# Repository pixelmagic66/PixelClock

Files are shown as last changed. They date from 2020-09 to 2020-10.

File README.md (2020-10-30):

# Pixelclock Dutch 11x9 1/4 

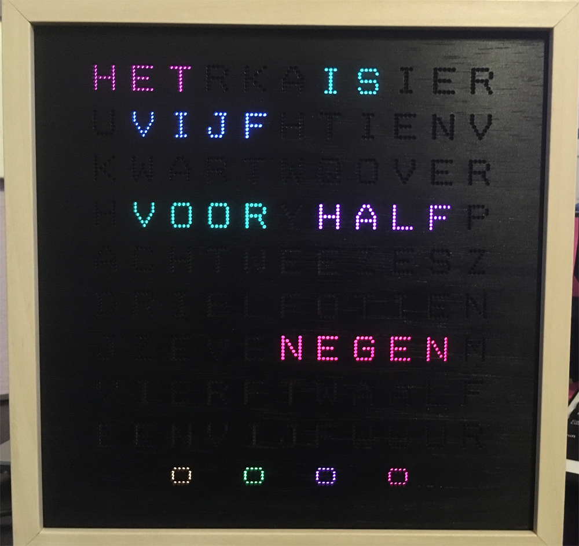
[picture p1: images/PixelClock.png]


Original software from https://github.com/bitlair/wordclock, all credits for the software and design go toward them.

Uses the now (2020) available Hovstra frame from Ikea https://www.ikea.com/nl/nl/p/hovsta-fotolijst-berkenpatroon-berken-80365755/

Adapted the internal frame structure and other font for the front of the clock.

I was a little bit puzzled by the uploading of the /data directory, this is what I did

- Follow the instructions from here: http://arduino.esp8266.com/Arduino/versions/2.0.0/doc/filesystem.html 
- I needed to set the adjust the flash size from 4mb to 3mb
- Upload the /data directory to SPIFFS (if I am correct), this takes some time

This is the other stuff you need te do:

- Upload the software from https://github.com/bitlair/wordclock or if you use my layout and connections use my code, using the Arduino IDE
- Connect your WS2812 led strip to the port specified in the code
- Configure the leds (if needed) in the leds tab of Arduino IDE
- Configure the words if you use other then I did (Dutch)
- Power up and via WiFi AP configure your WiFi network
- Enjoy the clock :)

The font I used is Dotrice found at https://www.1001fonts.com/dotrice-font.html if you need it for another language or layout, the svg file named Wordclock-face.svg

The first plan was to use spacers to add a white plexiglass layer to defuse the light. On the first test with this font and a piece of printer paper the defusion was good enough to not use the plexiglass. After that I redesigned the crossing layers to not use the spacers. 

So the order from back to front is:

- backplate with LED strips and wires on the back
- connecting brackets to isolate the LED's
- a piece of printer paper
- the frontplate, I spray painted it with black paint

Note on the svg files for the laser cutter, red lines ar cutting lines, blue lines are for etching (only used on the backside).

Materials I used:

- 103 pieces 60 led/meter WS2812 (AliExpress)
- Wemos type ESP8266
- 5 volt power brick
- 3mm bearch plywood (from the Gamma)
- Ikea Hovstra 23x23 photo frame
- black spraypaint (Ac-tion)

Tools used:

- Laser cutter (K40 type)
- K40 Whisperer
- Soldering iron
- Sanding paper
- Arduino IDE
- CorelDRAW! (for the front face)
- Inkscape (converting to usable date for K40 Whisperer)
- Fusion360 (the 3d design)

**

Uploading files to file system

ESP8266FS is a tool which integrates into the Arduino IDE. It adds a menu item to Tools menu for uploading the contents of sketch data directory into ESP8266 flash file system.

    Download the tool: https://github.com/esp8266/arduino-esp8266fs-plugin/releases/download/0.1.3/ESP8266FS-0.1.3.zip.
    In your Arduino sketchbook directory, create tools directory if it doesn't exist yet
    Unpack the tool into tools directory (the path will look like <home_dir>/Arduino/tools/ESP8266FS/tool/esp8266fs.jar)
    Restart Arduino IDE
    Open a sketch (or create a new one and save it)
    Go to sketch directory (choose Sketch > Show Sketch Folder)
    Create a directory named data and any files you want in the file system there
    Make sure you have selected a board, port, and closed Serial Monitor
    Select Tools > ESP8266 Sketch Data Upload. This should start uploading the files into ESP8266 flash file system. When done, IDE status bar will display SPIFFS Image Uploaded message.

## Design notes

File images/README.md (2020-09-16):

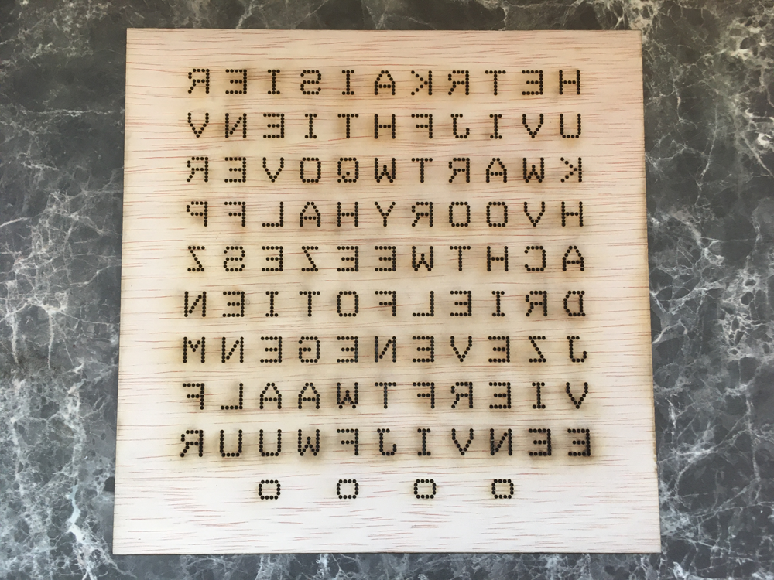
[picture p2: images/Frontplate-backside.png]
The backside of the front panel

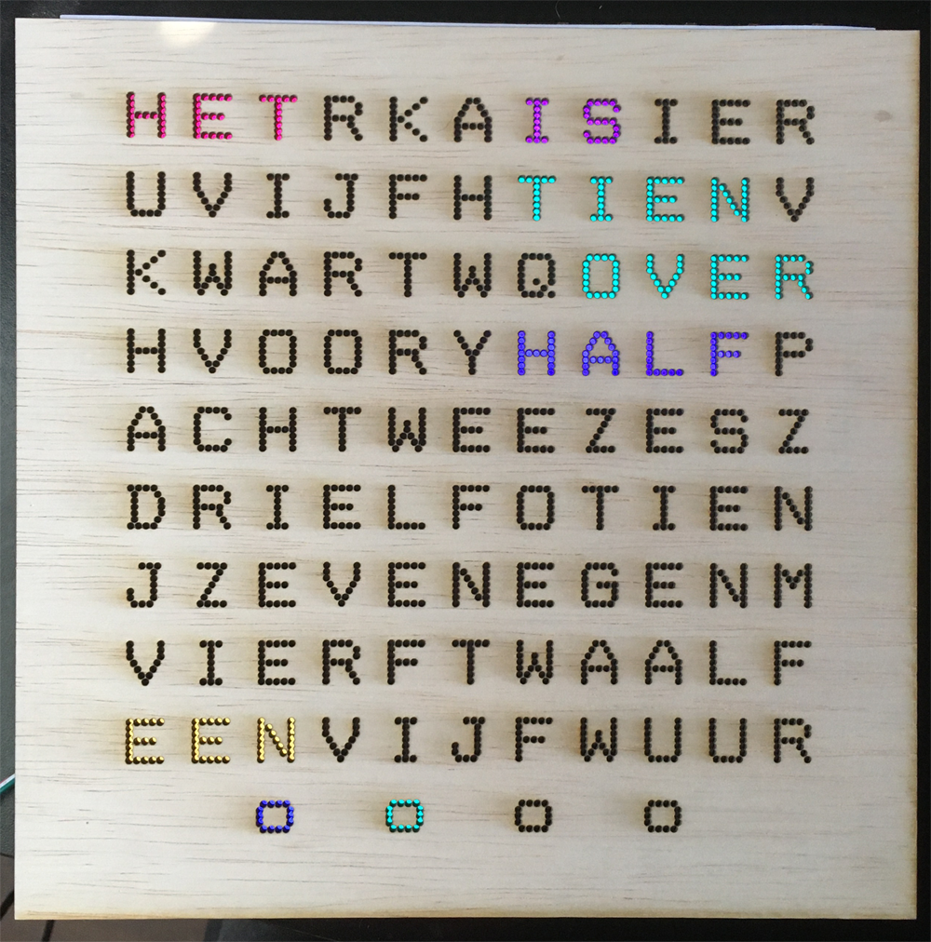
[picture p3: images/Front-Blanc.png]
The frontpanel without paint

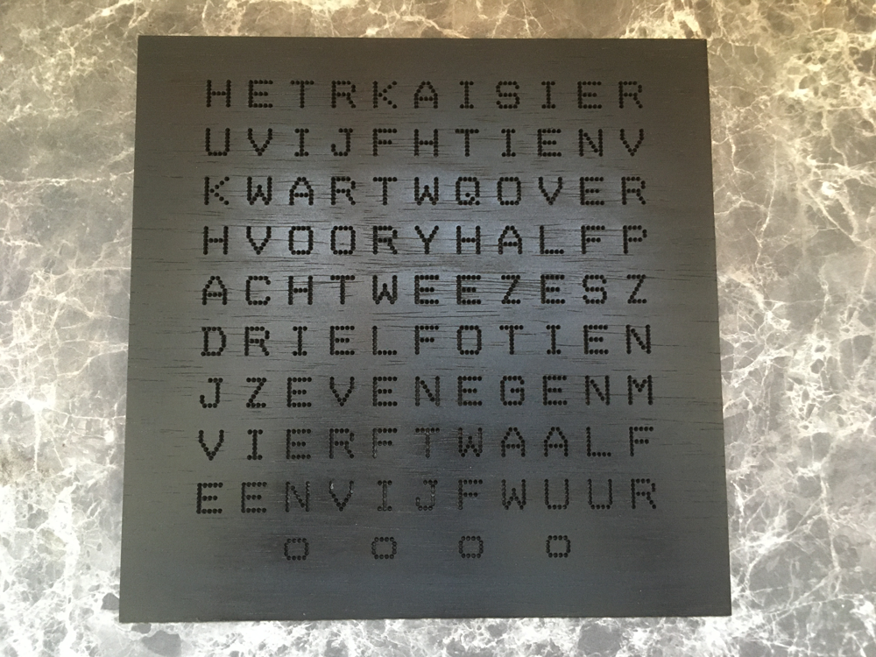
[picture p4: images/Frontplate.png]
The frontpanel with paint

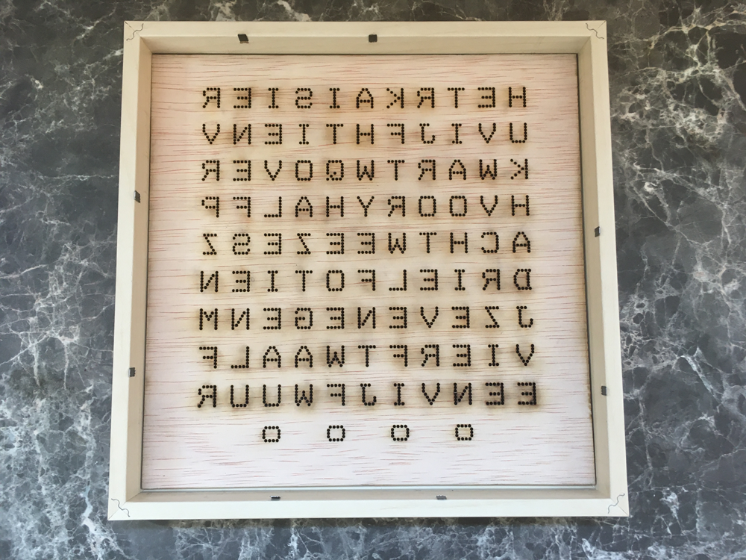
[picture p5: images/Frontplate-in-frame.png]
Frontpanel in the Ikea frame

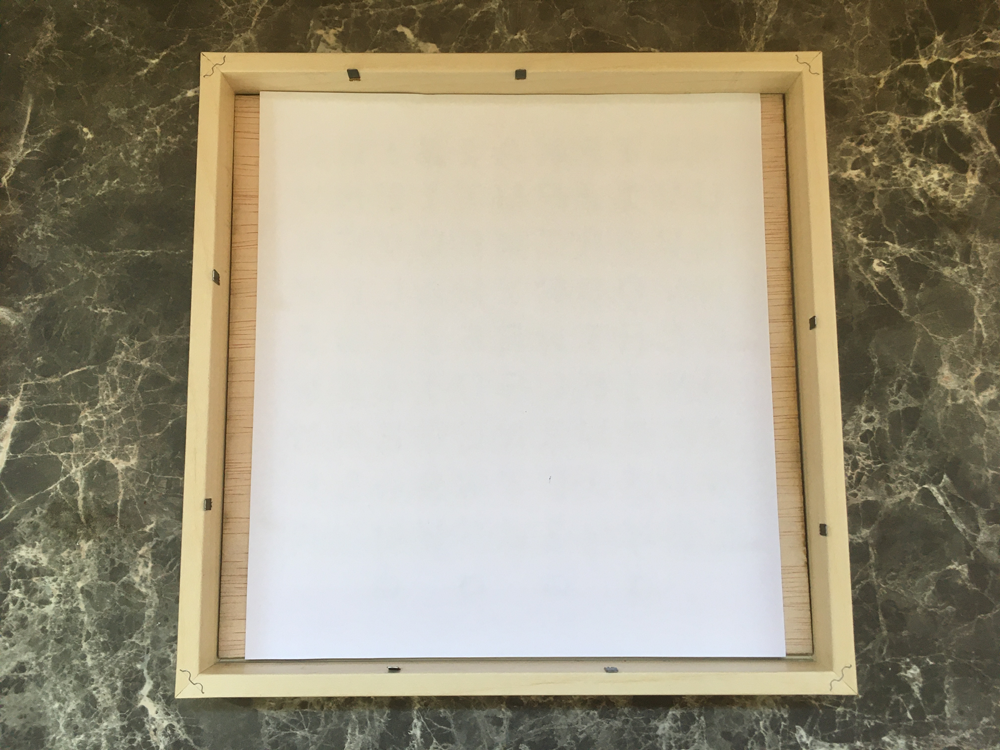
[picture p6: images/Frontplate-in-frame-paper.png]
A piece of printer paper to defuse the LEDs

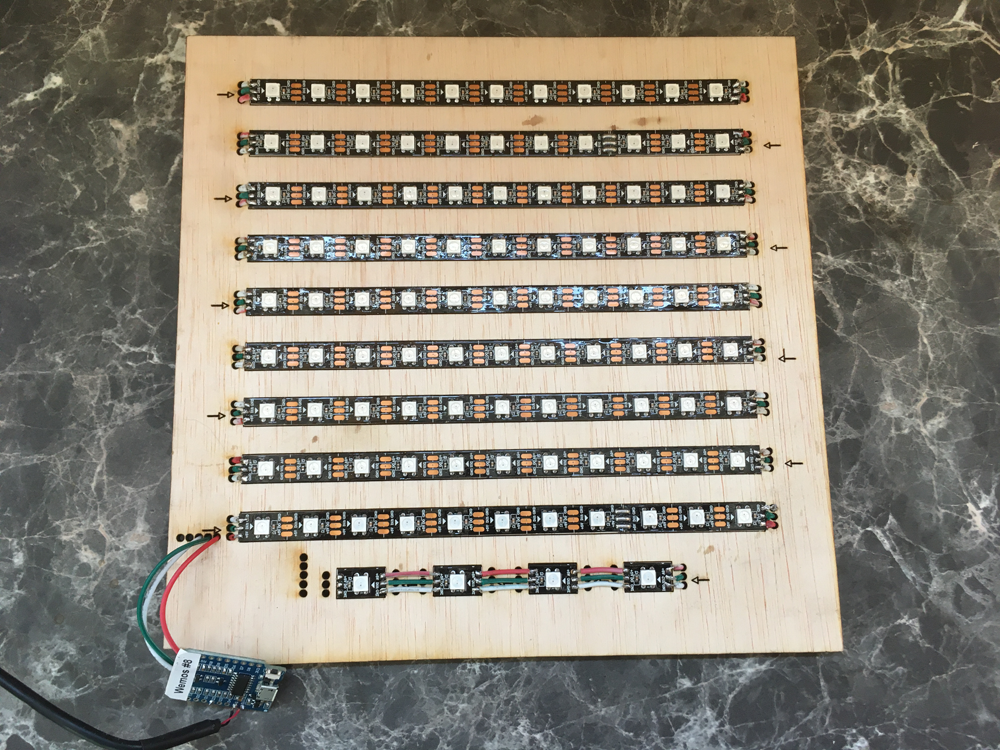
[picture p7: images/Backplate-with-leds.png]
The backplate with LED strips taped and soldered

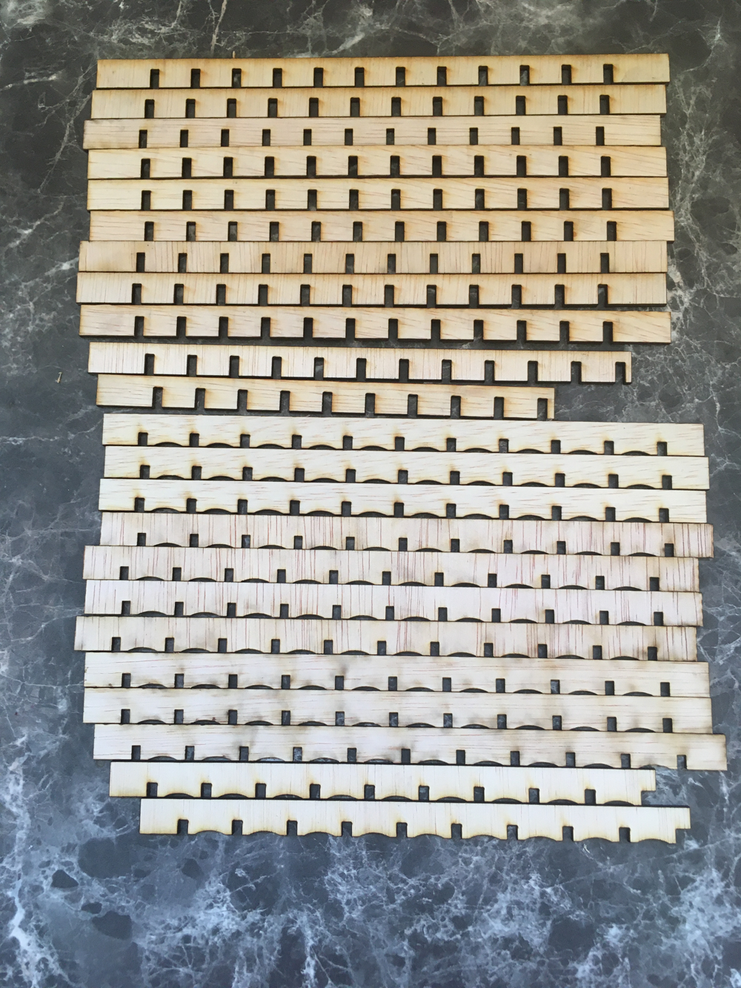
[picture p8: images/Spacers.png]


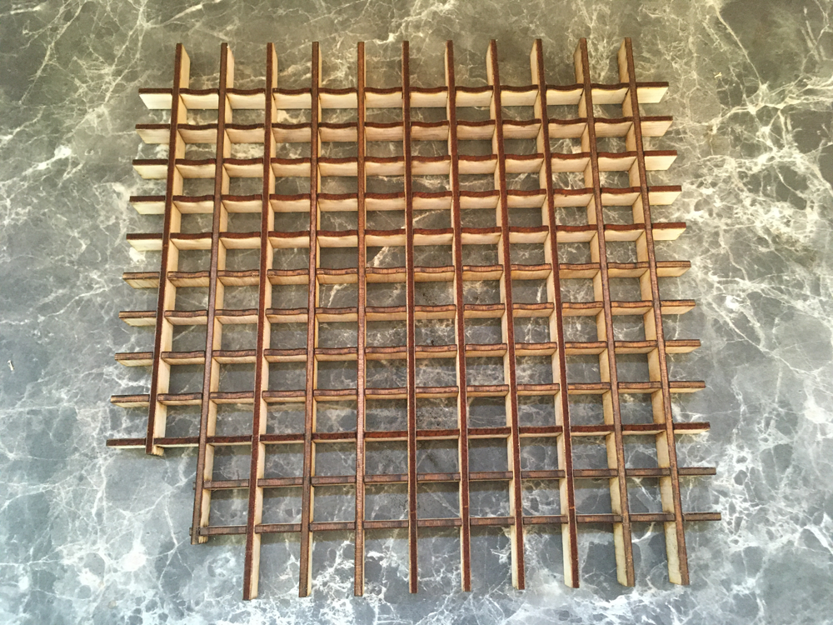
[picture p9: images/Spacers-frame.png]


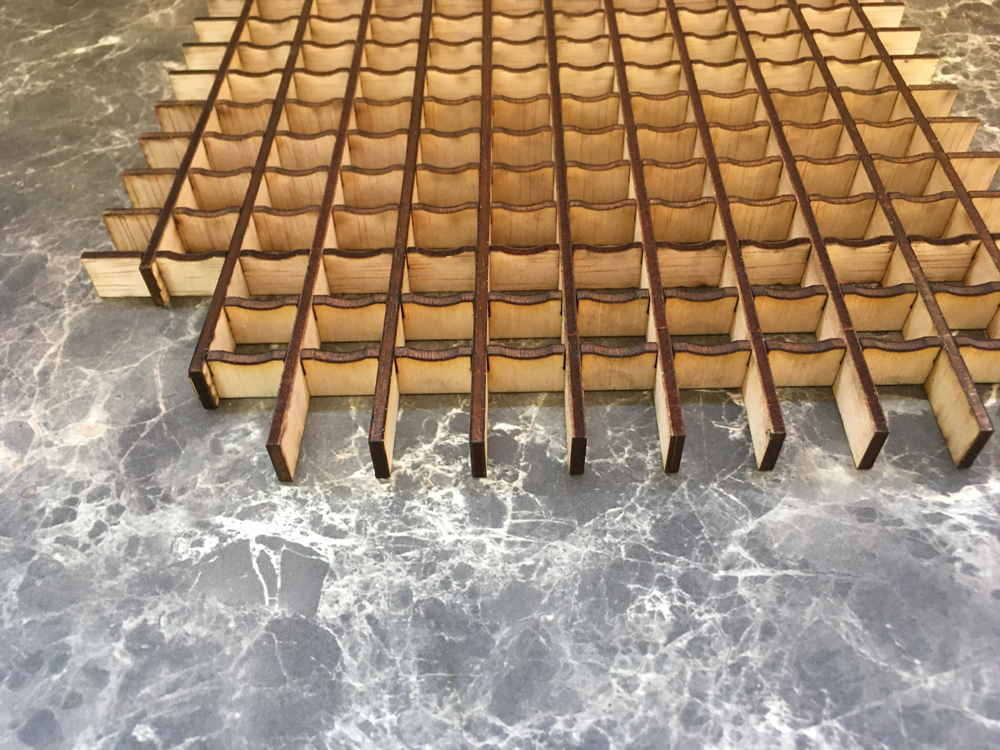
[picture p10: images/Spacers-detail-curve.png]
Beware of the curves for the LED strip, position in the correct way

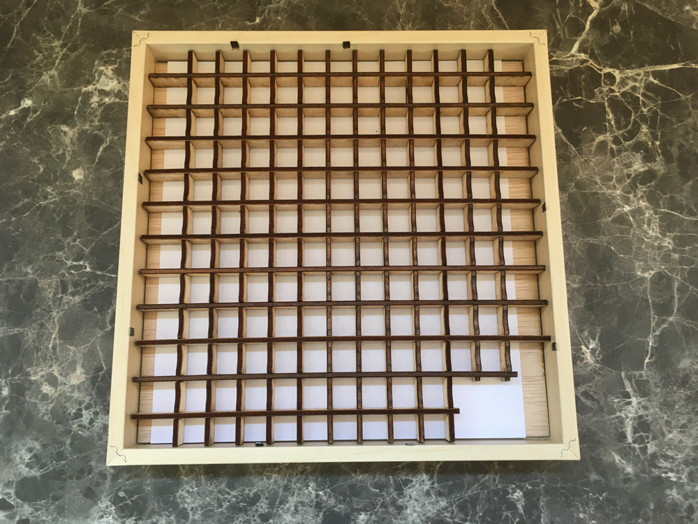
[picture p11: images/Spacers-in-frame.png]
The spacers in the frame, notice the space for the Wemos on the bottom right and the curvy spacing horizontal

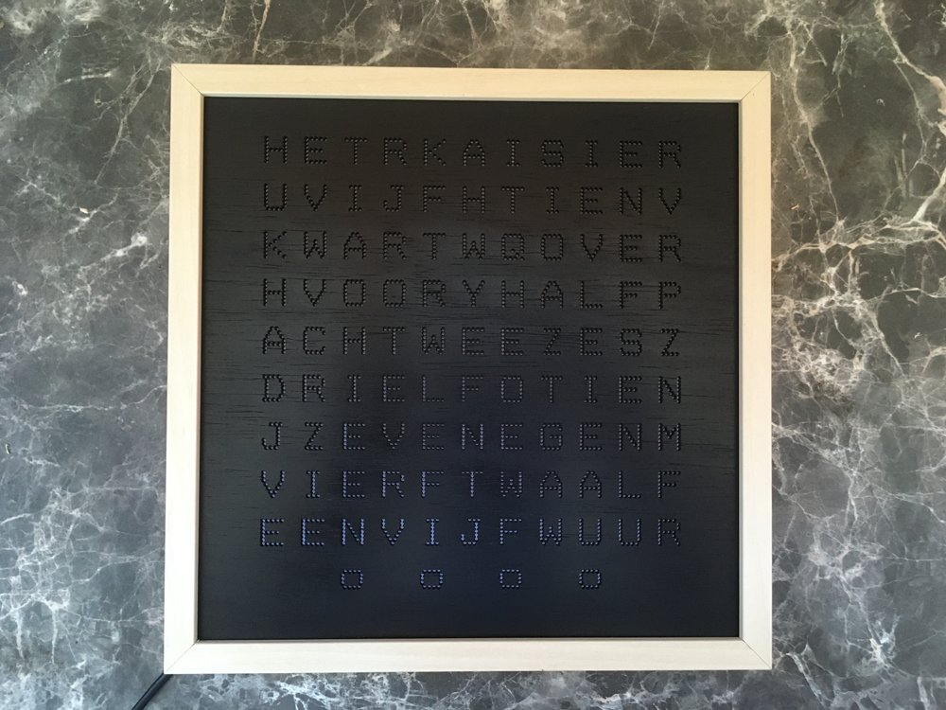
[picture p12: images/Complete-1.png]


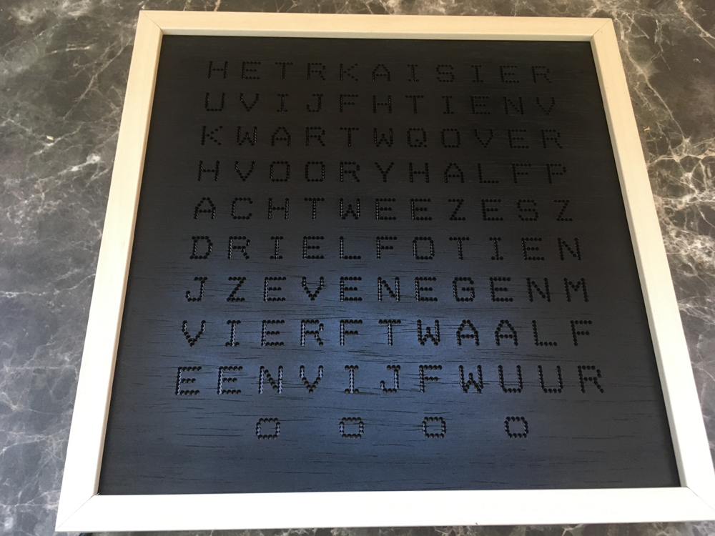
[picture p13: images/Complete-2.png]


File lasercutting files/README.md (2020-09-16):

Laser cutting files, I used a K40 with K40 whisperer software.

Cutting lines are red, engrave/etch lines are blue. The sizes are based upon 3mm thickness.

Horizontal-9x.svg           cut this 9 times

Horizontal1-1x.svg          cut this 1 time

Horizontal2-1x.svg          cut this 1 time

Vertical-10x.svg            cut this 10 times

Vertical-2x.svg             cut this 2 times

Wordclock-backplate.svg     cut this 1 time - this is the only one with engraving

Wordclock-face.svg          cut this 1 time

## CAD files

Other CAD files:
Fusion360/Wordclock-V1.f3z

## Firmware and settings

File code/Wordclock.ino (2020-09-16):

// Inspired by https://github.com/niekproductions/word-clock

// Required Libraries:
// - Arduino JSON (https://arduinojson.org/)
// - Time library (http://playground.arduino.cc/code/time)

// Web portal requires files on SPIFFS, please see the following URL for
// more information:

// http://esp8266.github.io/Arduino/versions/2.0.0/doc/filesystem.html

// deze versie is de werkende in de wordklok op 16-9-2020

#define FASTLED_ESP8266_RAW_PIN_ORDER
#define FASTLED_ALLOW_INTERRUPTS 0
#include <FastLED.h>
#include <TimeLib.h>
#include <vector>
#include <ESP8266WiFi.h>
#include "ESP8266HTTPUpdateServer.h"
#include "ArduinoJson.h"

const char *version = "0.1";

#define MAX_WIFI_NETWORKS 32
#define MAX_SSID_LENGTH 32
#define WIFI_NETWORK_UPDATE_INTERVAL 60000
#define HOSTNAME_MAX 256

struct WifiNetwork {
  char ssid[MAX_SSID_LENGTH + 1];
  uint8_t encryptionType;
  int32_t RSSI;
  int32_t channel;
  bool isHidden;
};

enum LedMode {
  single,
  words,
  hourly,
  rainbow
};

enum BrightnessMode {
  fixedBrightness,
  ldrBrightness,
  timeBrightness
};

struct Configuration {
  char ntp_server[256];
  char hostname[HOSTNAME_MAX];
  LedMode ledMode;
  uint8_t singleColorHue;
  uint8_t hourlyColors[24];
  uint8_t wordColors[25];
  BrightnessMode brightnessMode;
  uint8_t maxBrightness;
  uint8_t minBrightness;
  uint8_t brightnessStartHour;
  uint8_t brightnessEndHour;
  uint8_t checksum;
};

struct ClockfaceWord {
  std::vector<int> leds;
  int colorCodeInTable;
  bool (*isActive)(int, int);
};

Configuration config;

void setup() {
  // put your setup code here, to run once:
  Serial.begin(115200);
  Serial.print("Adapted from BITLAIR Wordclock, v");
  Serial.println(version);
  Serial.println("PixelClock 2020 https://github.com/pixelmagic66/PixelClock");
  Serial.print("ESP ID: ");
  Serial.println(String(ESP.getChipId()));

  configurationSetup();
  wifiSetup();
  webserverSetup();
  timeSetup();
  ledSetup();
}

void loop() {
  wifiLoop();
  webserverLoop();
  timeLoop();
  ledLoop();
}

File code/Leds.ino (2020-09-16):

#define LED_UPDATE_TIME 40
#define LED_TRANSITION_AMOUNT 15
#define LED_RAINBOW_TIME 1000

#define NUM_LEDS 103
#define DATA_PIN D2

#define LDR_PIN         A0
#define LDR_DARK        10
#define LDR_LIGHT       200
#define LDR_READ_DELAY  1000

CRGB leds[NUM_LEDS];
CRGB targetColors[NUM_LEDS];
long lastLedUpdate;

uint8_t ledState = 0;
int8_t ledScrollPosition = 0;
long ledScrollTime = 0;

long ledTestTime = 0;
uint8_t ledTestHue = 0;
int8_t ledTestWord = -1;

long ledRandomHue = 0;
long ledRandomTime = 0;

long ldrReadTime = 0;
int ldrValue = 0;

uint8_t ledMatrix[][11] = {
  {  0, 1, 2, 3, 4, 5, 6, 7, 8, 9,10 },
  { 21,20,19,18,17,16,15,14,13,12,11 },
  { 62,23,24,25,26,27,28,29,30,31,32 },
  { 43,42,41,40,39,38,37,36,35,34,33 },
  { 44,45,46,47,48,49,50,51,52,53,54 },
  { 65,64,63,62,61,60,59,58,57,56,55 },
  { 66,67,68,69,70,71,72,73,74,75,76 },
  { 87,86,85,84,83,82,81,80,79,78,77 },
  { 88,89,90,91,92,93,94,95,96,97,98 },
  { 102,101,100,99}
};

/*uint8_t startupText[][23] = {
  { 1,0,0,0,0,0,0,0,0,0,0,0,0,0,0,0,0,0,0,0,0,0,0 },
  { 1,0,0,0,0,0,1,0,0,0,1,0,0,0,0,0,0,0,0,0,0,0,0 },
  { 1,1,1,0,1,0,1,1,0,0,1,0,0,0,0,1,0,0,1,0,0,1,1 },
  { 1,0,1,0,1,0,1,0,0,0,1,0,0,0,0,0,1,0,1,0,1,0,0 },
  { 1,1,1,0,1,0,0,1,1,0,0,1,1,0,1,1,1,0,1,0,1,0,0 }
};*/

uint8_t startupText[][40] = {
  { 1,0,0,0,0,0,0,0,1,0,0,0,0,0,0,0,1,0,0,0,0,0,0,0,1,0,0,0,0,0,0,0,1,0,0,0,0,0,0,0  },
  { 0,1,0,0,0,0,0,1,0,1,0,0,0,0,0,1,0,1,0,0,0,0,0,1,0,1,0,0,0,0,0,1,0,1,0,0,0,0,0,0  },
  { 0,0,1,0,0,0,1,0,0,0,1,0,0,0,1,0,0,0,1,0,0,0,1,0,0,0,1,0,0,0,1,0,0,0,1,0,0,0,0,0  },
  { 0,0,0,1,0,1,0,0,0,0,0,1,0,1,0,0,0,0,0,1,0,1,0,0,0,0,0,1,0,1,0,0,0,0,0,1,0,0,0,0  },
    { 0,0,0,1,0,1,0,0,0,0,0,1,0,1,0,0,0,0,0,1,0,1,0,0,0,0,0,1,0,1,0,0,0,0,0,1,0,0,0,0  },
  { 0,0,0,0,1,0,0,0,0,0,0,0,1,0,0,0,0,0,0,0,1,0,0,0,0,0,0,0,1,0,0,0,0,0,0,0,1,0,0,0  }
};  

void ledSetup() {
  FastLED.addLeds<WS2812B, DATA_PIN, GRB>(leds, NUM_LEDS);

  for(int i = 0; i < NUM_LEDS; i++) {
    leds[i] = CRGB::Black;
  }

  FastLED.show();

  ledScrollPosition = -sizeof(ledMatrix[0]);
}

void nblendU8TowardU8( uint8_t& cur, const uint8_t target, uint8_t amount)
{
  if( cur == target) return;
  
  if( cur < target ) {
    uint8_t delta = target - cur;
    delta = scale8_video( delta, amount);
    cur += delta;
  } else {
    uint8_t delta = cur - target;
    delta = scale8_video( delta, amount);
    cur -= delta;
  }
}

CRGB fadeTowardColor(CRGB &cur, const CRGB &target, uint8_t amount)
{
  nblendU8TowardU8( cur.red,   target.red,   amount);
  nblendU8TowardU8( cur.green, target.green, amount);
  nblendU8TowardU8( cur.blue,  target.blue,  amount);
  return cur;
}

long switchTime;
int state;

byte calculateTimeBrightness() {
    if (hour() > config.brightnessStartHour && hour() < config.brightnessEndHour) {
        return config.maxBrightness;
    } else if (hour() < config.brightnessStartHour || hour() > config.brightnessEndHour) {
        return config.minBrightness;
    } else if (hour() == config.brightnessStartHour) {
        return constrain(
                map(minute(), 0, 29, config.minBrightness, config.maxBrightness),
                config.minBrightness, config.maxBrightness);
    } else if (hour() == config.brightnessEndHour) {
        return constrain(
                map(minute(), 0, 29, config.maxBrightness, config.minBrightness),
                config.minBrightness, config.maxBrightness);
    }
}

byte lastBrightness;
byte ledBrightness() {
  byte targetBrightness = config.maxBrightness;
  switch(config.brightnessMode) {
    case fixedBrightness: targetBrightness = config.maxBrightness; break;
    case timeBrightness: targetBrightness = calculateTimeBrightness(); break;
    case ldrBrightness: targetBrightness = constrain(
                map(ldrValue, LDR_DARK, LDR_LIGHT, config.minBrightness, config.maxBrightness),
                config.minBrightness, config.maxBrightness); break;
  }

  if (lastBrightness == 0) {
    lastBrightness = targetBrightness;
  } else {
    int difference = abs(targetBrightness - lastBrightness);
    if (targetBrightness > lastBrightness) {
        lastBrightness = lastBrightness + (1 + 30 * difference / 189 );
    }else if (targetBrightness < lastBrightness) {
        lastBrightness = lastBrightness - (1 + 30 * difference / 189 );
    }
  }

  return lastBrightness;
}

void ledFadeToAssignedColors() {
  if ((millis() - lastLedUpdate) > LED_UPDATE_TIME) {
    lastLedUpdate = millis();

    for(int i = 0; i < NUM_LEDS; i++) {
      fadeTowardColor(leds[i], targetColors[i], LED_TRANSITION_AMOUNT);
    }

    FastLED.show(ledBrightness());
  }
}

void ledScrollIntro() {
  if ((millis() - ledScrollTime) > 250) {  
    ledScrollTime = millis();
    
    for(int y = 0; y < 5; y++) {
      for(int x = 0; x < sizeof(ledMatrix[y]); x++) {
        uint8_t isActive = ((x + ledScrollPosition < sizeof(startupText[y])) && (x + ledScrollPosition >= 0)) ? 
          startupText[y][x + ledScrollPosition] : 0;
          
        CRGB color = isActive ? CRGB(255, 25, 0) : CRGB::Black;
        uint8_t position = ledMatrix[y + 2][x];
        leds[position] = color;
      }
    }
    FastLED.show(ledBrightness());

    int8_t scrollsize = (sizeof(startupText[0]) + sizeof(ledMatrix[0]));
    ledScrollPosition++;
    if (ledScrollPosition > scrollsize) ledState++;
  }
}

void ledShowClockface() {
  time_t t = now();

  for(int i = 0; i < NUM_LEDS; i++) {
    targetColors[i] = CRGB::Black;
  }

  CRGB color = CRGB::Black;
  switch(config.ledMode) {
    case single: color.setHue(config.singleColorHue); break;
    case hourly: color.setHue(config.hourlyColors[hour()]); break;
    case rainbow: color.setHue(ledRandomHue); break;
  }

  for(ClockfaceWord word : clockface) {
    if (word.isActive(hour() % 12, minute())) {
      for(int pos : word.leds) {
        if (config.ledMode != words) {
          targetColors[pos] = color; 
        } else {
          targetColors[pos].setHue(config.wordColors[word.colorCodeInTable]);
        }
      }
    }
  }
}

void ledShowTestColor() {
  for(int i = 0; i < NUM_LEDS; i++) {
    leds[i] = CRGB::Black;
  }

  for(ClockfaceWord word : clockface) {
    if (ledTestWord == -1) {
      if (word.isActive(hour() % 12, minute())) {
        for(int pos : word.leds) {
          leds[pos].setHue(ledTestHue);
        }
      }
    } else {
      if (word.colorCodeInTable == ledTestWord) {
        for(int pos : word.leds) {
          leds[pos].setHue(ledTestHue);
        }
      }
    }
  }
  FastLED.show(ledBrightness());  
}

void ledShowNoWifiStatus() {
  if ((millis() - lastLedUpdate) > LED_UPDATE_TIME) {
    lastLedUpdate = millis();

    for(int i = 0; i < NUM_LEDS; i++) {
      leds[i] = CRGB::Black;
    }
    leds[102] = CRGB::Red;
    FastLED.show(ledBrightness());  
  }
}
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

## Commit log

2020-09-16 Lasercutting file - cut this one 9 times
    [Horizontal-9x.dxf]
2020-09-16 Lasercutting file - cut this one 1 time
    [Horizontal1-1x.dxf]
2020-09-16 Lasercutting file - cut this one 10 times
    [Vertical-10x.dxf]
2020-09-16 Lasercutting file - cut this one 2 times
    [Vertical-2x.dxf]
2020-09-16 The Fusion360 file of the clock, without the front plate
    For anyone that wants to change some things
    [Wordclock-V1.f3z]
2020-09-16 Laser cutting files
